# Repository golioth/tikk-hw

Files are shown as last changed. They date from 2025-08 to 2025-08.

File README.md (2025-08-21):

# Tikk Bluetooth Sensor / Output Board

We created the Tikk board as an affordable* board ($15 in low volume) for displaying the capabilities of Golioth's Bluetooth Connectivity. It plugs into a low cost ($3) Tenstar Robot nRF52840 breakout board, targeted at Keybord makers. We will have many of these nodes surrounding a Golioth gateway to showcase all of the uplink and downlink functions available to users. The focus was on easily demonstrated functions, such as LEDs and motor drivings for outputs and various in-tree Zephyr supported sensors for inputs.

## Rev A Preview Image




## Rev A Photos

Tikk-RevA-Back

Tikk-RevA-Front

## Features

This board has the following characteristics when soldered to something like the Tenstar Promicro

* 105 LEDs in 0402 format, individually addressable in a 7x15 matrix with the IS31FL3731
* Two H-Bridge chips (L9110S) for driving a single stepper or two dc motors
* 3 axis accelerometer (LIS2DH12)
* Temperature sensor (TMP102)
* QWIIC / Stemma header to expand breakout boards*
* User button
* Reset button
* A voltage divider that monitors battery voltage

Additional capabilities added by the Tenstar ProMicro and nRF52840

* Additional GPIOs I can solder to (5 digital, one analog)
* LiPo battery charger on board
* Load switch for all peripherals except motor driver
* USB Input to the nRF52840 (get serial terminal using USB-CDC)
* NFC tag emulation (via the nRF52840 and onboard flex connector)

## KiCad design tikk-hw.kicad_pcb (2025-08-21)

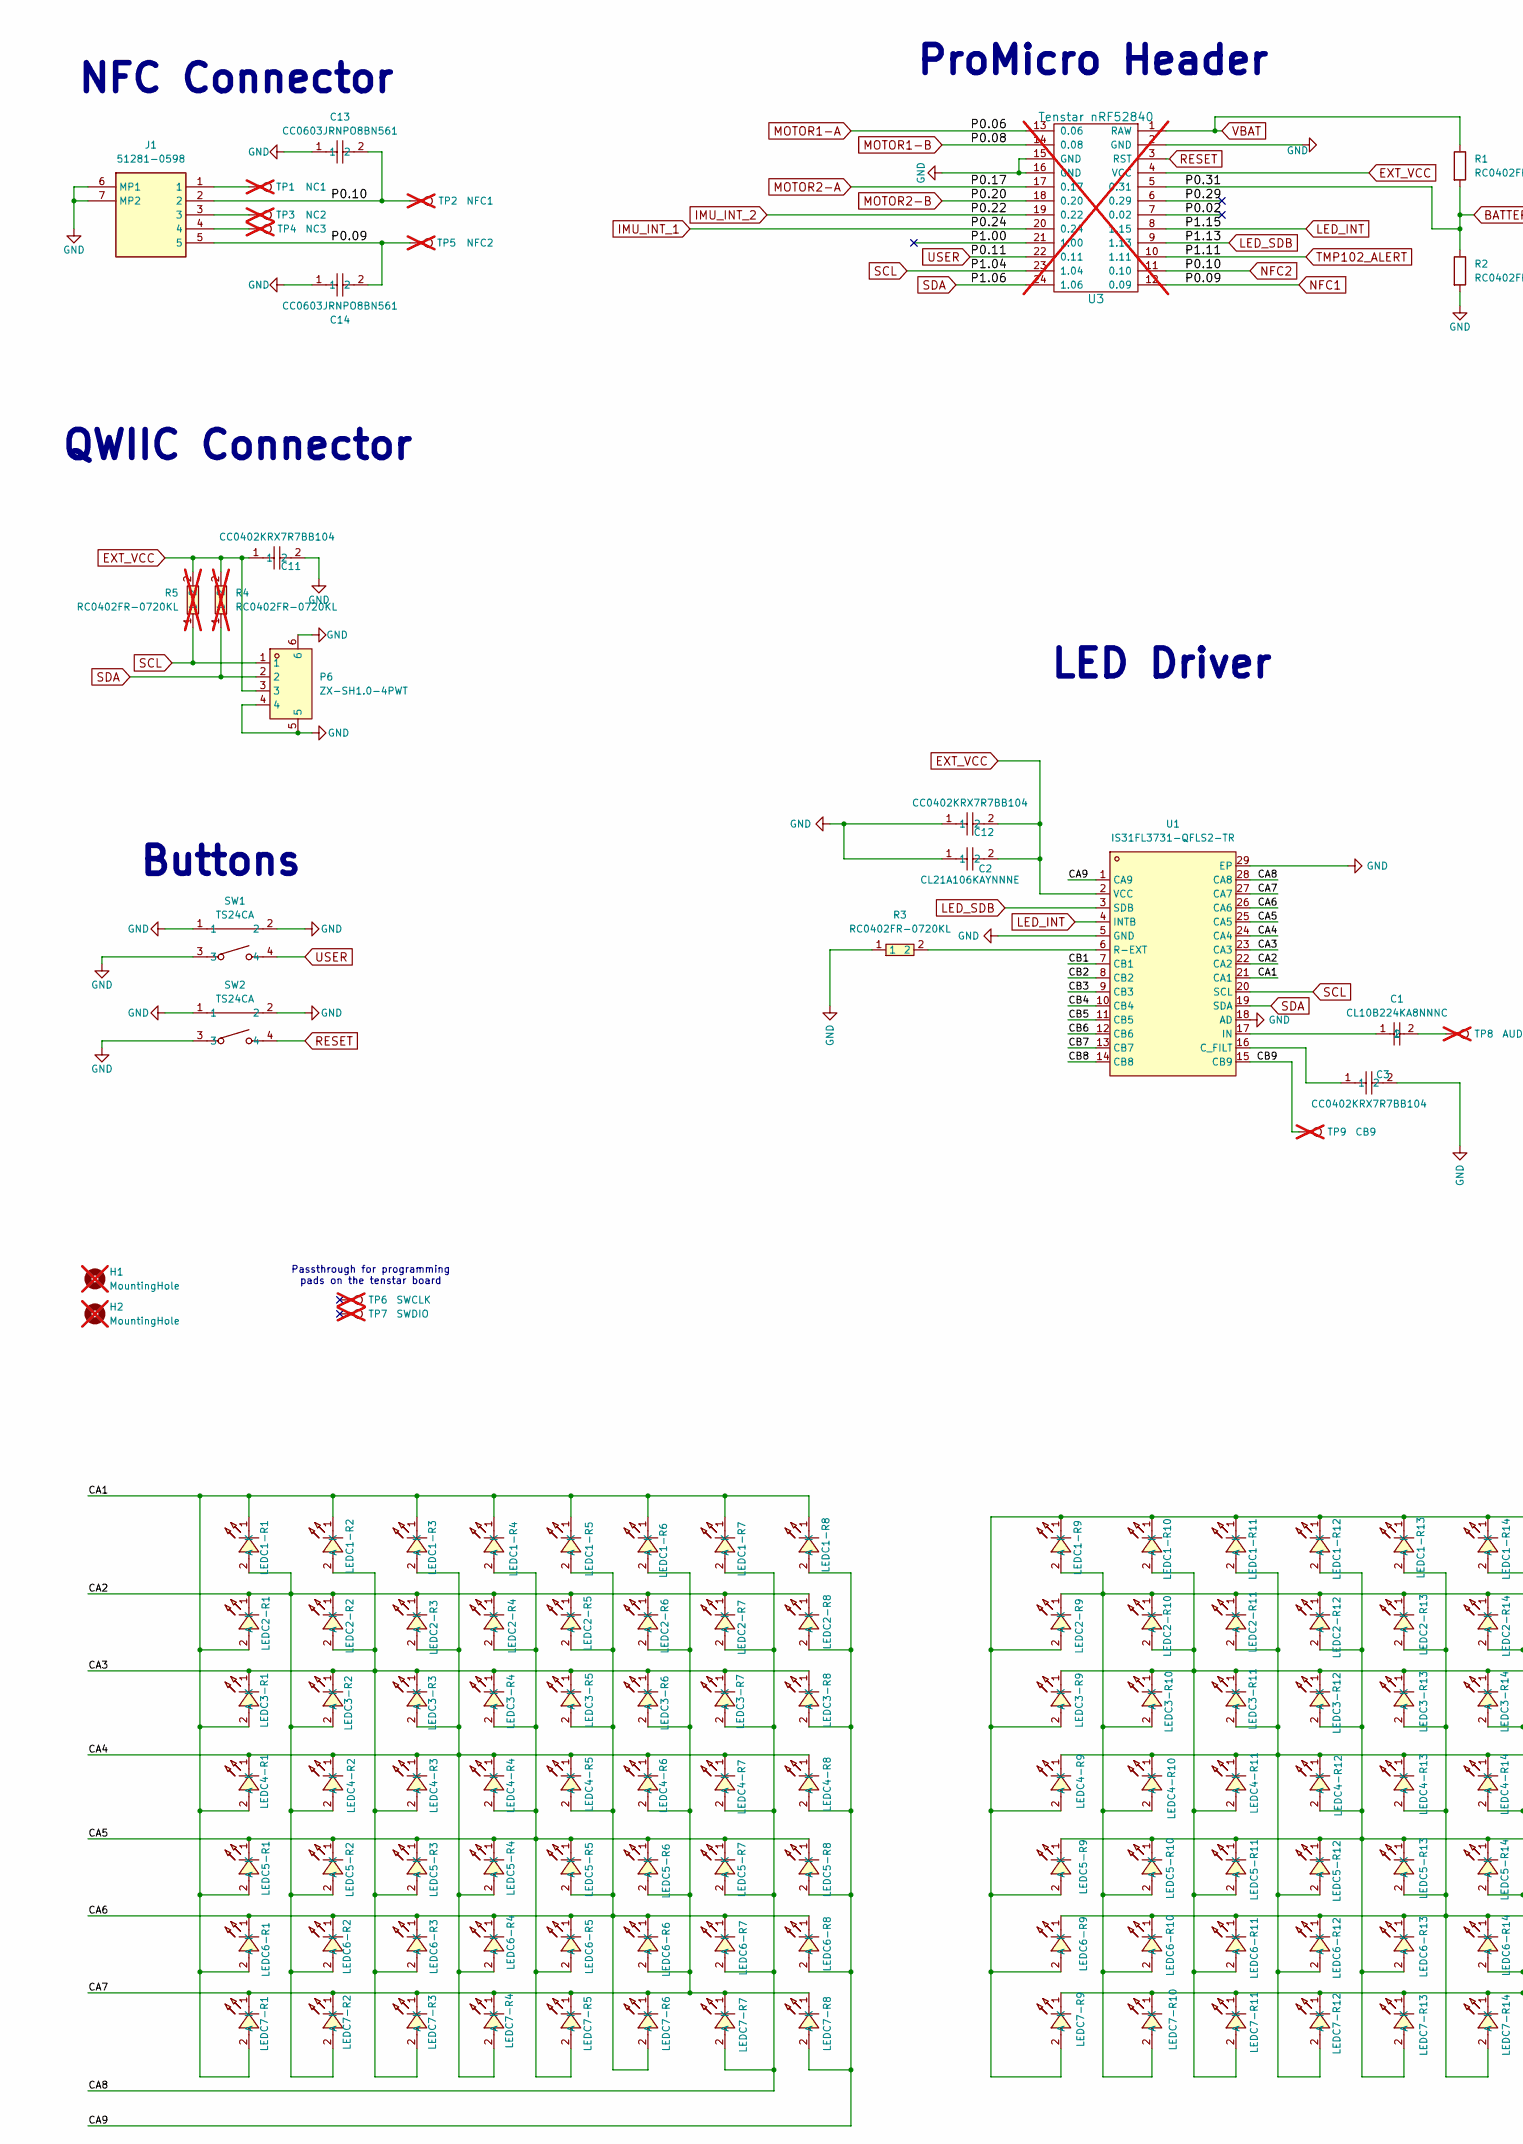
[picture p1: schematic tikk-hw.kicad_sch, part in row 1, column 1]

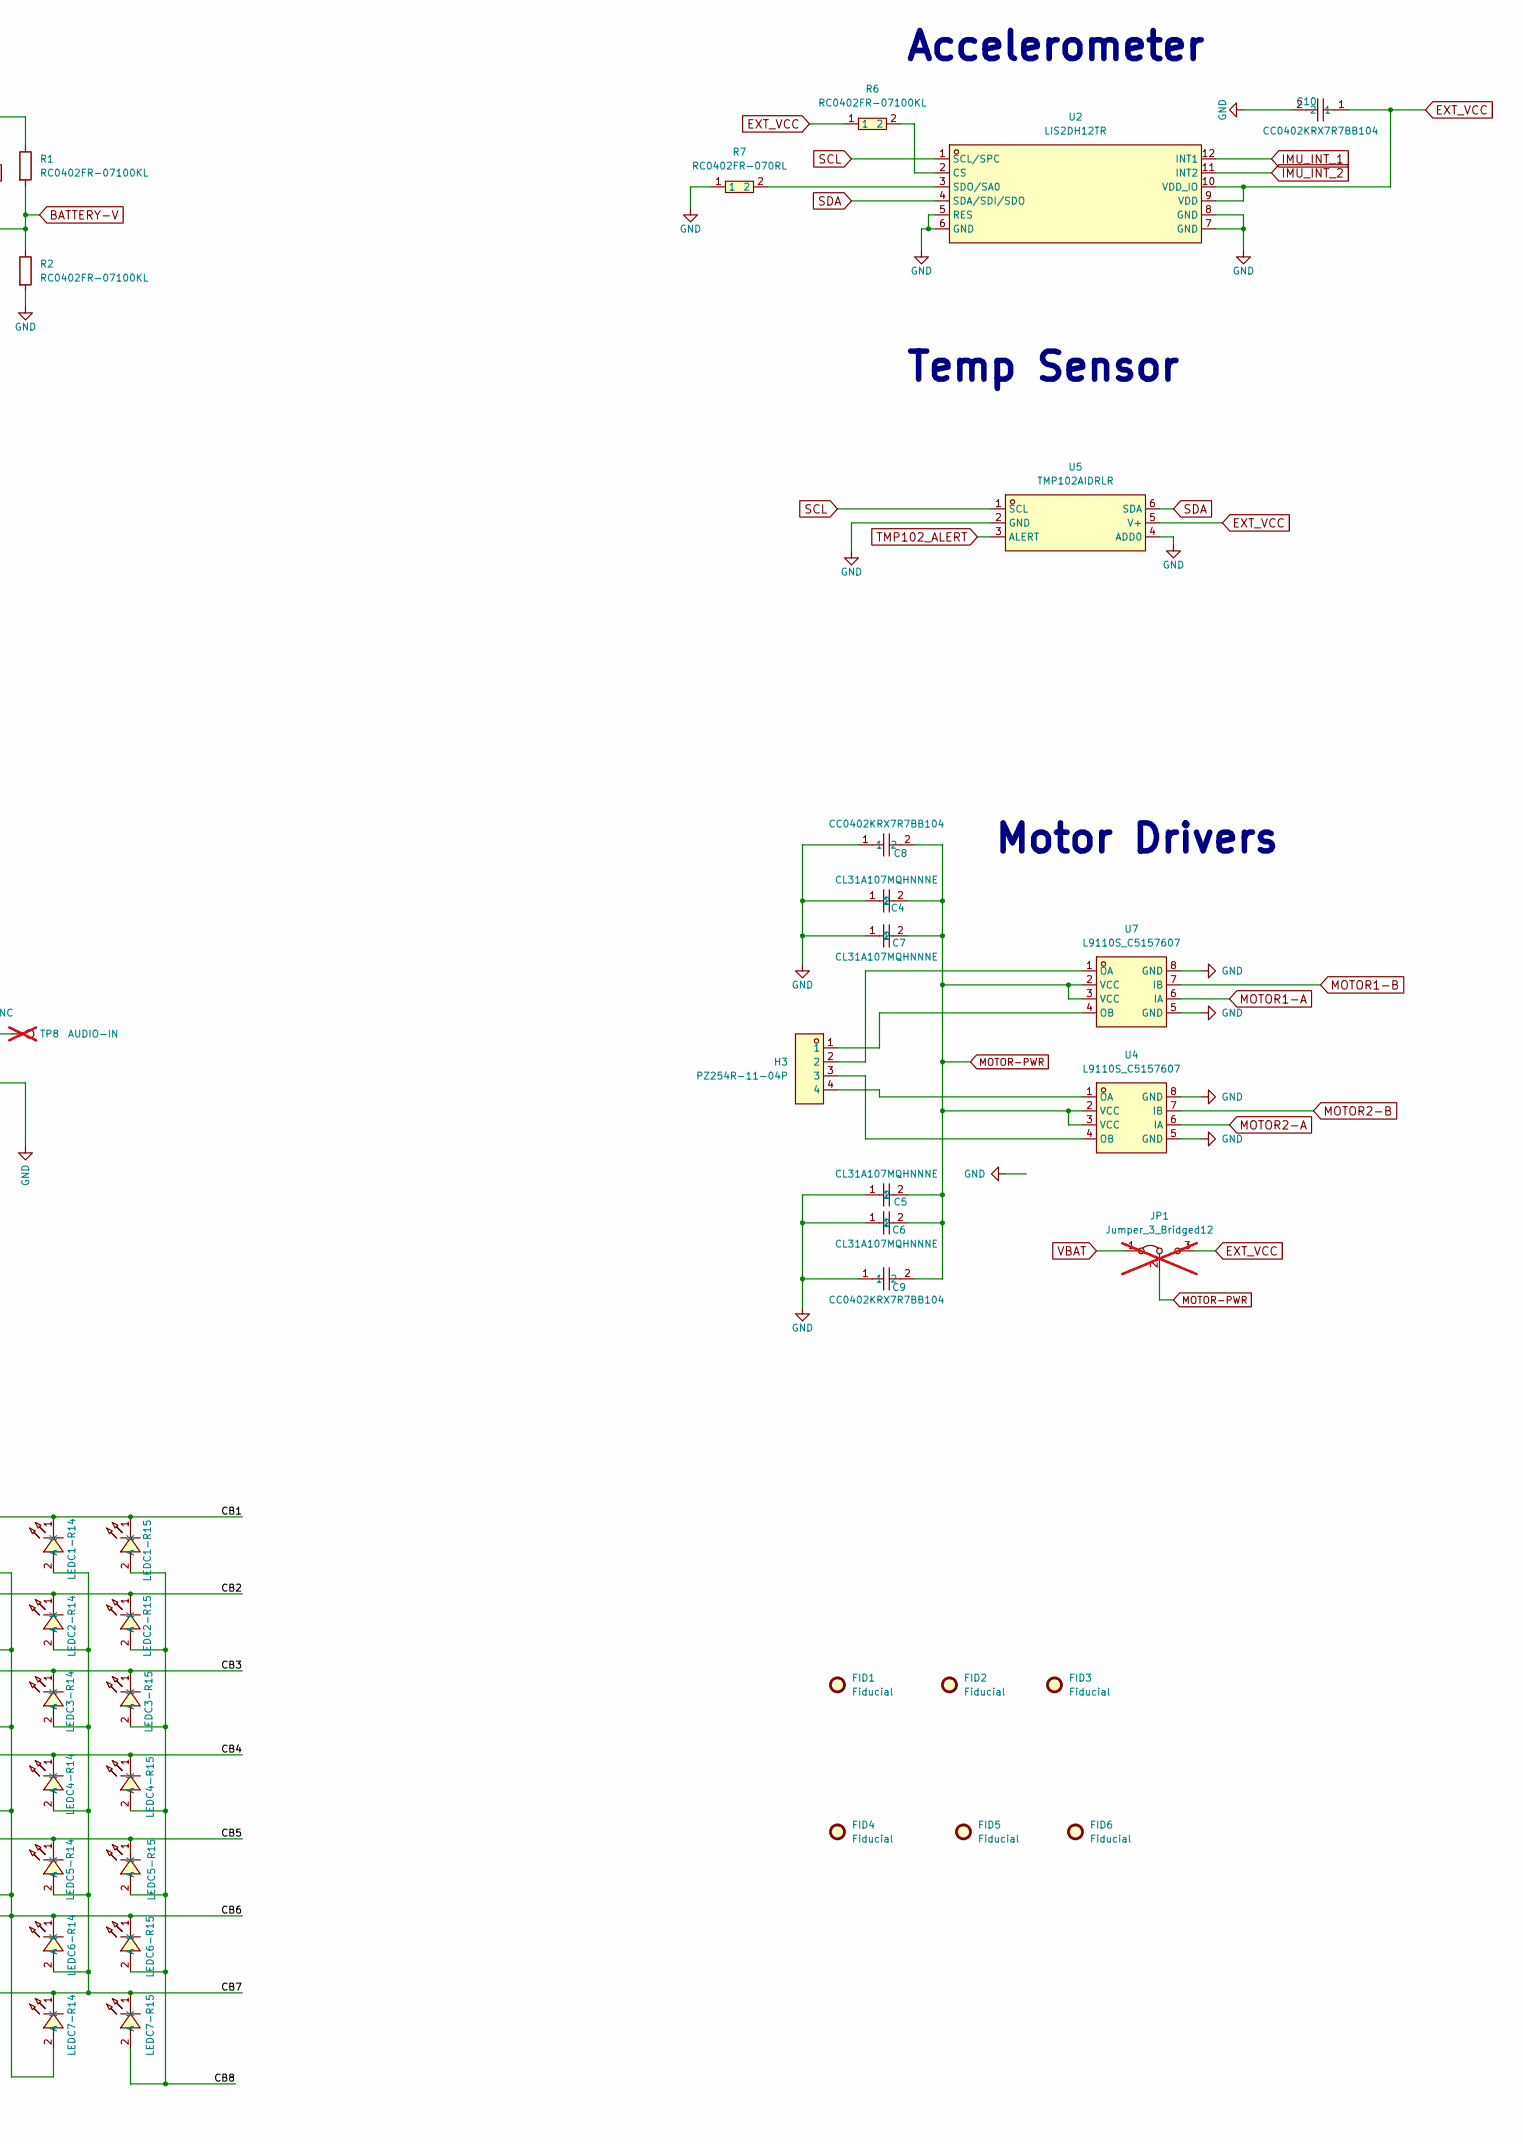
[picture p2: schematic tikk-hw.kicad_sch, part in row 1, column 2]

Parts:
C1: CL10B224KA8NNNC; C0603; LCSC Part C21120
C2: CL21A106KAYNNNE; C0805; LCSC Part C15850
C3, C8, C9, C10, C11, C12: CC0402KRX7R7BB104; C0402; LCSC Part C60474
C4, C5, C6, C7: CL31A107MQHNNNE; C1206; LCSC Part C15008
C13, C14: CC0603JRNPO8BN561; C0603; LCSC Part C519396
FID1, FID2, FID3, FID4, FID5, FID6: Fiducial; Fiducial_0.5mm_Mask1mm
H1, H2: MountingHole; MountingHole_2.1mm; not fitted
H3: PZ254R-11-04P; HDR-TH_4P-P2.54-H-M-W10.4; LCSC Part C492412
J1: 51281-0598; 512810598; Mouser Part Number 538-51281-0598
JP1: Jumper_3_Bridged12; SolderJumper-3_P1.3mm_Bridged12_Pad1.0x1.5mm_NumberLabels; not fitted
LEDC1-R1, LEDC1-R2, LEDC1-R3, LEDC1-R4, LEDC1-R5, LEDC1-R6, LEDC1-R7, LEDC1-R8, LEDC1-R9, LEDC1-R10, LEDC1-R11, LEDC1-R12, LEDC1-R13, LEDC1-R14, LEDC1-R15, LEDC2-R1, LEDC2-R2, LEDC2-R3, LEDC2-R4, LEDC2-R5, LEDC2-R6, LEDC2-R7, LEDC2-R8, LEDC2-R9, LEDC2-R10, LEDC2-R11, LEDC2-R12, LEDC2-R13, LEDC2-R14, LEDC2-R15, LEDC3-R1, LEDC3-R2, LEDC3-R3, LEDC3-R4, LEDC3-R5, LEDC3-R6, LEDC3-R7, LEDC3-R8, LEDC3-R9, LEDC3-R10, LEDC3-R11, LEDC3-R12, LEDC3-R13, LEDC3-R14, LEDC3-R15, LEDC4-R1, LEDC4-R2, LEDC4-R3, LEDC4-R4, LEDC4-R5, LEDC4-R6, LEDC4-R7, LEDC4-R8, LEDC4-R9, LEDC4-R10, LEDC4-R11, LEDC4-R12, LEDC4-R13, LEDC4-R14, LEDC4-R15, LEDC5-R1, LEDC5-R2, LEDC5-R3, LEDC5-R4, LEDC5-R5, LEDC5-R6, LEDC5-R7, LEDC5-R8, LEDC5-R9, LEDC5-R10, LEDC5-R11, LEDC5-R12, LEDC5-R13, LEDC5-R14, LEDC5-R15, LEDC6-R1, LEDC6-R2, LEDC6-R3, LEDC6-R4, LEDC6-R5, LEDC6-R6, LEDC6-R7, LEDC6-R8, LEDC6-R9, LEDC6-R10, LEDC6-R11, LEDC6-R12, LEDC6-R13, LEDC6-R14, LEDC6-R15, LEDC7-R1, LEDC7-R2, LEDC7-R3, LEDC7-R4, LEDC7-R5, LEDC7-R6, LEDC7-R7, LEDC7-R8, LEDC7-R9, LEDC7-R10, LEDC7-R11, LEDC7-R12, LEDC7-R13, LEDC7-R14, LEDC7-R15: F.0402.00003/P2-0402R1TS2-045T-001; LED0402-RD; LCSC Part C7496803
P6: ZX-SH1.0-4PWT; CONN-SMD_4P-P1.00_MEGASTAR_ZX-SH1.0-4PWT; LCSC Part C7430446
R1, R2: RC0402FR-07100KL; R_0402_1005Metric
R3: RC0402FR-0720KL; R0402; LCSC Part C93942
R4, R5: RC0402FR-0720KL; R0402; LCSC Part C93942; not fitted
R6: RC0402FR-07100KL; R0402; LCSC Part C60491
R7: RC0402FR-070RL; R0402; LCSC Part C106231
SW1, SW2: TS24CA; SW-SMD_TS24CA; LCSC Part C393942
TP1: NC1; TestPoint_Pad_1.0x1.0mm; not fitted
TP2: NFC1; TestPoint_Pad_1.0x1.0mm; not fitted
TP3: NC2; TestPoint_Pad_1.0x1.0mm; not fitted
TP4: NC3; TestPoint_Pad_1.0x1.0mm; not fitted
TP5: NFC2; TestPoint_Pad_1.0x1.0mm; not fitted
TP6: SWCLK; TestPoint_THTPad_1.0x1.0mm_Drill0.5mm; not fitted
TP7: SWDIO; TestPoint_THTPad_1.0x1.0mm_Drill0.5mm; not fitted
TP8: AUDIO-IN; TestPoint_Pad_D1.0mm; not fitted
TP9: CB9; TestPoint_Pad_D1.0mm; not fitted
U1: IS31FL3731-QFLS2-TR; QFN-28_L4.0-W4.0-P0.40-BL-EP; LCSC Part C191206
U2: LIS2DH12TR; LGA-12_L2.0-W2.0-P0.50-BL; LCSC Part C110926
U3: Tenstar nRF52840; tenstar_nrf52840; not fitted
U4, U7: L9110S_C5157607; SOP-8_L4.9-W3.9-P1.27-LS6.0-BL; LCSC Part C5157607
U5: TMP102AIDRLR; SOT-563_L1.6-W1.2-P0.50-LS1.6-BR; LCSC Part C99269

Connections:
/CA1: LEDC1-R1.1 (K), LEDC1-R2.1 (K), LEDC1-R3.1 (K), LEDC1-R4.1 (K), LEDC1-R5.1 (K), LEDC1-R6.1 (K), LEDC1-R7.1 (K), LEDC1-R8.1 (K), LEDC2-R1.2 (A), LEDC3-R1.2 (A), LEDC4-R1.2 (A), LEDC5-R1.2 (A), LEDC6-R1.2 (A), LEDC7-R1.2 (A), U1.21 (CA1)
/CA2: LEDC1-R1.2 (A), LEDC2-R1.1 (K), LEDC2-R2.1 (K), LEDC2-R3.1 (K), LEDC2-R4.1 (K), LEDC2-R5.1 (K), LEDC2-R6.1 (K), LEDC2-R7.1 (K), LEDC2-R8.1 (K), LEDC3-R2.2 (A), LEDC4-R2.2 (A), LEDC5-R2.2 (A), LEDC6-R2.2 (A), LEDC7-R2.2 (A), U1.22 (CA2)
/CA3: LEDC1-R2.2 (A), LEDC2-R2.2 (A), LEDC3-R1.1 (K), LEDC3-R2.1 (K), LEDC3-R3.1 (K), LEDC3-R4.1 (K), LEDC3-R5.1 (K), LEDC3-R6.1 (K), LEDC3-R7.1 (K), LEDC3-R8.1 (K), LEDC4-R3.2 (A), LEDC5-R3.2 (A), LEDC6-R3.2 (A), LEDC7-R3.2 (A), U1.23 (CA3)
/CA4: LEDC1-R3.2 (A), LEDC2-R3.2 (A), LEDC3-R3.2 (A), LEDC4-R1.1 (K), LEDC4-R2.1 (K), LEDC4-R3.1 (K), LEDC4-R4.1 (K), LEDC4-R5.1 (K), LEDC4-R6.1 (K), LEDC4-R7.1 (K), LEDC4-R8.1 (K), LEDC5-R4.2 (A), LEDC6-R4.2 (A), LEDC7-R4.2 (A), U1.24 (CA4)
/CA5: LEDC1-R4.2 (A), LEDC2-R4.2 (A), LEDC3-R4.2 (A), LEDC4-R4.2 (A), LEDC5-R1.1 (K), LEDC5-R2.1 (K), LEDC5-R3.1 (K), LEDC5-R4.1 (K), LEDC5-R5.1 (K), LEDC5-R6.1 (K), LEDC5-R7.1 (K), LEDC5-R8.1 (K), LEDC6-R5.2 (A), LEDC7-R5.2 (A), U1.25 (CA5)
/CA6: LEDC1-R5.2 (A), LEDC2-R5.2 (A), LEDC3-R5.2 (A), LEDC4-R5.2 (A), LEDC5-R5.2 (A), LEDC6-R1.1 (K), LEDC6-R2.1 (K), LEDC6-R3.1 (K), LEDC6-R4.1 (K), LEDC6-R5.1 (K), LEDC6-R6.1 (K), LEDC6-R7.1 (K), LEDC6-R8.1 (K), LEDC7-R6.2 (A), U1.26 (CA6)
/CA7: LEDC1-R6.2 (A), LEDC2-R6.2 (A), LEDC3-R6.2 (A), LEDC4-R6.2 (A), LEDC5-R6.2 (A), LEDC6-R6.2 (A), LEDC7-R1.1 (K), LEDC7-R2.1 (K), LEDC7-R3.1 (K), LEDC7-R4.1 (K), LEDC7-R5.1 (K), LEDC7-R6.1 (K), LEDC7-R7.1 (K), LEDC7-R8.1 (K), U1.27 (CA7)
/CA8: LEDC1-R7.2 (A), LEDC2-R7.2 (A), LEDC3-R7.2 (A), LEDC4-R7.2 (A), LEDC5-R7.2 (A), LEDC6-R7.2 (A), LEDC7-R7.2 (A), U1.28 (CA8)
/CA9: LEDC1-R8.2 (A), LEDC2-R8.2 (A), LEDC3-R8.2 (A), LEDC4-R8.2 (A), LEDC5-R8.2 (A), LEDC6-R8.2 (A), LEDC7-R8.2 (A), U1.1 (CA9)
/CB1: LEDC1-R9.1 (K), LEDC1-R10.1 (K), LEDC1-R11.1 (K), LEDC1-R12.1 (K), LEDC1-R13.1 (K), LEDC1-R14.1 (K), LEDC1-R15.1 (K), LEDC2-R9.2 (A), LEDC3-R9.2 (A), LEDC4-R9.2 (A), LEDC5-R9.2 (A), LEDC6-R9.2 (A), LEDC7-R9.2 (A), U1.7 (CB1)
/CB2: LEDC1-R9.2 (A), LEDC2-R9.1 (K), LEDC2-R10.1 (K), LEDC2-R11.1 (K), LEDC2-R12.1 (K), LEDC2-R13.1 (K), LEDC2-R14.1 (K), LEDC2-R15.1 (K), LEDC3-R10.2 (A), LEDC4-R10.2 (A), LEDC5-R10.2 (A), LEDC6-R10.2 (A), LEDC7-R10.2 (A), U1.8 (CB2)
/CB3: LEDC1-R10.2 (A), LEDC2-R10.2 (A), LEDC3-R9.1 (K), LEDC3-R10.1 (K), LEDC3-R11.1 (K), LEDC3-R12.1 (K), LEDC3-R13.1 (K), LEDC3-R14.1 (K), LEDC3-R15.1 (K), LEDC4-R11.2 (A), LEDC5-R11.2 (A), LEDC6-R11.2 (A), LEDC7-R11.2 (A), U1.9 (CB3)
/CB4: LEDC1-R11.2 (A), LEDC2-R11.2 (A), LEDC3-R11.2 (A), LEDC4-R9.1 (K), LEDC4-R10.1 (K), LEDC4-R11.1 (K), LEDC4-R12.1 (K), LEDC4-R13.1 (K), LEDC4-R14.1 (K), LEDC4-R15.1 (K), LEDC5-R12.2 (A), LEDC6-R12.2 (A), LEDC7-R12.2 (A), U1.10 (CB4)
/CB5: LEDC1-R12.2 (A), LEDC2-R12.2 (A), LEDC3-R12.2 (A), LEDC4-R12.2 (A), LEDC5-R9.1 (K), LEDC5-R10.1 (K), LEDC5-R11.1 (K), LEDC5-R12.1 (K), LEDC5-R13.1 (K), LEDC5-R14.1 (K), LEDC5-R15.1 (K), LEDC6-R13.2 (A), LEDC7-R13.2 (A), U1.11 (CB5)
/CB6: LEDC1-R13.2 (A), LEDC2-R13.2 (A), LEDC3-R13.2 (A), LEDC4-R13.2 (A), LEDC5-R13.2 (A), LEDC6-R9.1 (K), LEDC6-R10.1 (K), LEDC6-R11.1 (K), LEDC6-R12.1 (K), LEDC6-R13.1 (K), LEDC6-R14.1 (K), LEDC6-R15.1 (K), LEDC7-R14.2 (A), U1.12 (CB6)
/CB7: LEDC1-R14.2 (A), LEDC2-R14.2 (A), LEDC3-R14.2 (A), LEDC4-R14.2 (A), LEDC5-R14.2 (A), LEDC6-R14.2 (A), LEDC7-R9.1 (K), LEDC7-R10.1 (K), LEDC7-R11.1 (K), LEDC7-R12.1 (K), LEDC7-R13.1 (K), LEDC7-R14.1 (K), LEDC7-R15.1 (K), U1.13 (CB7)
/CB8: LEDC1-R15.2 (A), LEDC2-R15.2 (A), LEDC3-R15.2 (A), LEDC4-R15.2 (A), LEDC5-R15.2 (A), LEDC6-R15.2 (A), LEDC7-R15.2 (A), U1.14 (CB8)
/CB9: TP9.1, U1.15 (CB9)
/P0.02: U3.7 (0.02)
/P0.29: U3.6 (0.29)
/P1.00: U3.21 (1.00)
BATTERY-V: R1.2, R2.1, U3.5 (0.31)
EXT_VCC: C2.2, C10.1, C11.1, C12.2, JP1.3 (B), P6.3, R4.2, R5.2, R6.1, U1.2 (VCC), U2.9 (VDD), U2.10 (VDD_IO), U3.4 (VCC), U5.5 (V+)
GND: C2.1, C3.2, C4.1, C5.1, C6.1, C7.1, C8.1, C9.1, C10.2, C11.2, C12.1, C13.1, C14.1, J1.6 (MP1), J1.7 (MP2), P6.4, P6.5, P6.6, R2.2, R3.1, R7.1, SW1.1, SW1.2, SW1.3, SW2.1, SW2.2, SW2.3, U1.5 (GND), U1.18 (AD), U1.29 (EP), U2.5 (RES), U2.6 (GND), U2.7 (GND), U2.8 (GND), U3.2 (GND), U3.15 (GND), U3.16 (GND), U4.5 (GND), U4.8 (GND), U5.2 (GND), U5.4 (ADD0), U7.5 (GND), U7.8 (GND)
IMU_INT_1: U2.12 (INT1), U3.20 (0.24)
IMU_INT_2: U2.11 (INT2), U3.19 (0.22)
LED_INT: U1.4 (INTB), U3.8 (1.15)
LED_SDB: U1.3 (SDB), U3.9 (1.13)
MOTOR1-A: U3.13 (0.06), U7.6 (IA)
MOTOR1-B: U3.14 (0.08), U7.7 (IB)
MOTOR2-A: U3.17 (0.17), U4.6 (IA)
MOTOR2-B: U3.18 (0.20), U4.7 (IB)
MOTOR-PWR: C4.2, C5.2, C6.2, C7.2, C8.2, C9.2, JP1.2 (C), U4.2 (VCC), U4.3 (VCC), U7.2 (VCC), U7.3 (VCC)
NFC1: C14.2, J1.5, TP5.1, U3.12 (0.09)
NFC2: C13.2, J1.2, TP2.1, U3.11 (0.10)
unnamed: C1.2, TP8.1
unnamed: J1.1, TP1.1
unnamed: J1.3, TP3.1
unnamed: J1.4, TP4.1
unnamed: C3.1, U1.16 (C_FILT)
unnamed: C1.1, U1.17 (IN)
unnamed: R3.2, U1.6 (R-EXT)
unnamed: R6.2, U2.2 (CS)
unnamed: R7.2, U2.3 (SDO/SA0)
unnamed: H3.4, U4.1 (OA)
unnamed: H3.3, U4.4 (OB)
unnamed: H3.2, U7.1 (OA)
unnamed: H3.1, U7.4 (OB)
RESET: SW2.4, U3.3 (RST)
SCL: P6.1, R5.1, U1.20 (SCL), U2.1 (SCL/SPC), U3.23 (1.04), U5.1 (SCL)
SDA: P6.2, R4.1, U1.19 (SDA), U2.4 (SDA/SDI/SDO), U3.24 (1.06), U5.6 (SDA)
TMP102_ALERT: U3.10 (1.11), U5.3 (ALERT)
USER: SW1.4, U3.22 (0.11)
VBAT: JP1.1 (A), R1.1, U3.1 (RAW)

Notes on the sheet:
Accelerometer
NFC Connector
Temp Sensor
LED Driver
Passthrough for programming pads on the tenstar board
Motor Drivers
Buttons
QWIIC Connector
ProMicro Header

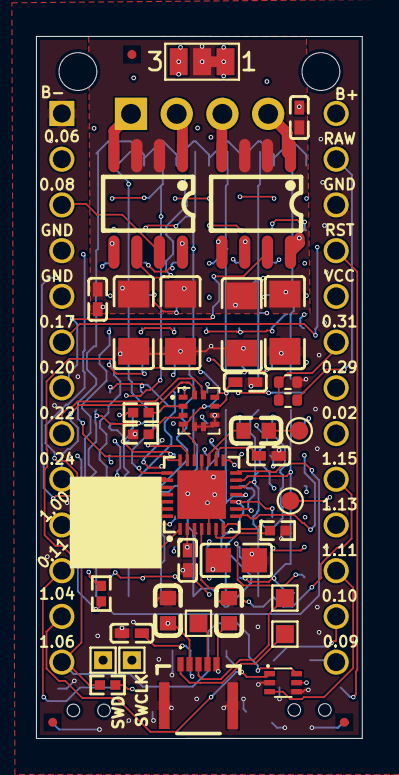
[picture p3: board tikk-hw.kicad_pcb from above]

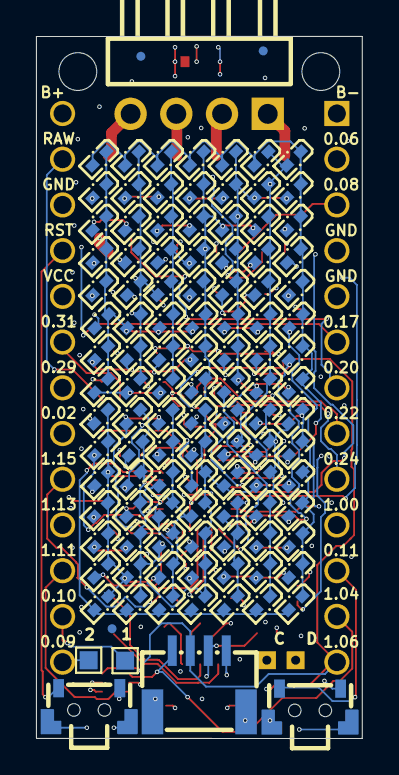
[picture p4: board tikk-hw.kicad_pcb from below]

Board: 4 copper layers, 18.1 x 39.0 mm, 155 parts (116 on the bottom side), 51 nets.

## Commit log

2025-07-08 initial board concept
    [tikk-hw.kicad_pcb, tikk-hw.kicad_sch]
2025-07-11 initial placements all finished
    [tikk-hw.kicad_pcb, tikk-hw.kicad_sch]
2025-07-12 added caps
    [tikk-hw.kicad_pcb, tikk-hw.kicad_sch]
2025-07-16 midway through routing LED matrix
    [tikk-hw.kicad_pcb, tikk-hw.kicad_sch]
2025-07-16 all connections to LEDs made on schematics
    [tikk-hw.kicad_pcb, tikk-hw.kicad_sch]
2025-07-17 finished initial layout
    [tikk-hw.kicad_pcb, tikk-hw.kicad_sch]
2025-07-18 Removed all initial DRC violations
    [tikk-hw.kicad_pcb, tikk-hw.kicad_sch]
2025-07-18 updated to add silkscreen qr code area and optimized component info
    [tikk-hw.kicad_pcb, tikk-hw.kicad_sch]
2025-07-18 add fiducials for mfg
    [tikk-hw.kicad_pcb, tikk-hw.kicad_sch]
2025-07-22 final changes before sending to JLC
    [tikk-hw.kicad_pcb, tikk-hw.kicad_sch]
2025-07-28 fix node assignment for user button (listed as 0.13, actually is 0.11)
    [tikk-hw.kicad_pcb, tikk-hw.kicad_sch]
2025-08-21 Clean up repo before open sourcing, pull in final data changes on schematic
    [tikk-hw.kicad_pcb, tikk-hw.kicad_sch]
